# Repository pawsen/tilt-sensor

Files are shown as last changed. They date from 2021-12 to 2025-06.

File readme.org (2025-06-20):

#+TITLE: Readme

# Note that #+PROPERTY lines do not automatically take effect. You should either re-open the file or press C-c C-c on the line.
#+PROPERTY: ATTACH_DIR misc
#+PROPERTY: ATTACH_DIR_INHERIT t

Use an arduino for converting the output of an accelerometer to an angle of inclination.

* TL;DR

- Add 4.7㏀ as pullups between =SDA=, =SCL= and =Vcc= ::
  4-wire cables to connect the Arduino, LCD and accelerometer, =Vcc=, =gnd=, =SDA= and =SCL=.
  Use a small piece of stripboard to connect the cables:
  4 strips with minimum 5 rows. The rows are: pullups, accelerometer, arduino, power and connecting cable.
  On the Arduino:
  - =A4 - SDA=
  - =A5 - SCL=
- Update [[file:combined/combined.ino][combined.ino]] ::
  Run the accelerometer 2g test [[file:misc/calibrate/calibrate.ino][calibrate.ino]] to get the min/max static accelerations for the three axis and update the values
  - Optionally, use [[file:misc/i2c_scanner/i2c_scanner.ino][ic2_scanner.ino]] to get the addresses. If they are the default values, only the acceleration min/max values have to be updated.
  - Optionally, set the [[https://lastminuteengineers.com/i2c-lcd-arduino-tutorial/#i2c-address-of-lcd][I2C address of the LCD]]. The default is =0x27=.
  - Optionally, set the I2C address of the accelerometer. If it is [[*Accelerometer, ADXL345][ADXL345]], the default is =0x53=
- Optionally, print the cases in the =stl= directory

The cable between the two boxes can be a cat5 network cable (low-ish capacitance).
- one pair ground, one pair +5V, and SDA+GND and SCL+GND pairs.

In the =combined= directory run
#+begin_src sh
make upload
# open the serial console
tio -b 9600 /dev/ttyUSB0
#+end_src

The assembled system looks like
#+CAPTION: Display and sensor.
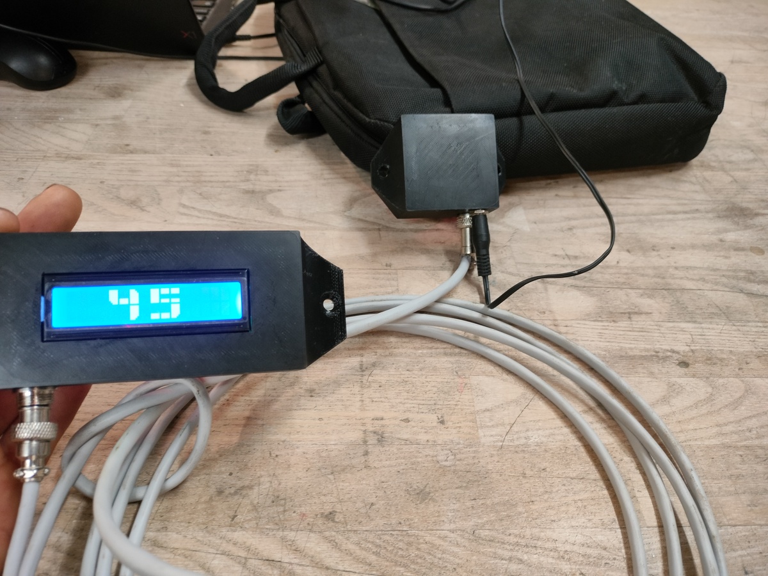
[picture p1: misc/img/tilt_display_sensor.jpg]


#+CAPTION: Backside of the LCD: 4-wire connection to I2C shield (PCF8574) for the 1602 LCD display
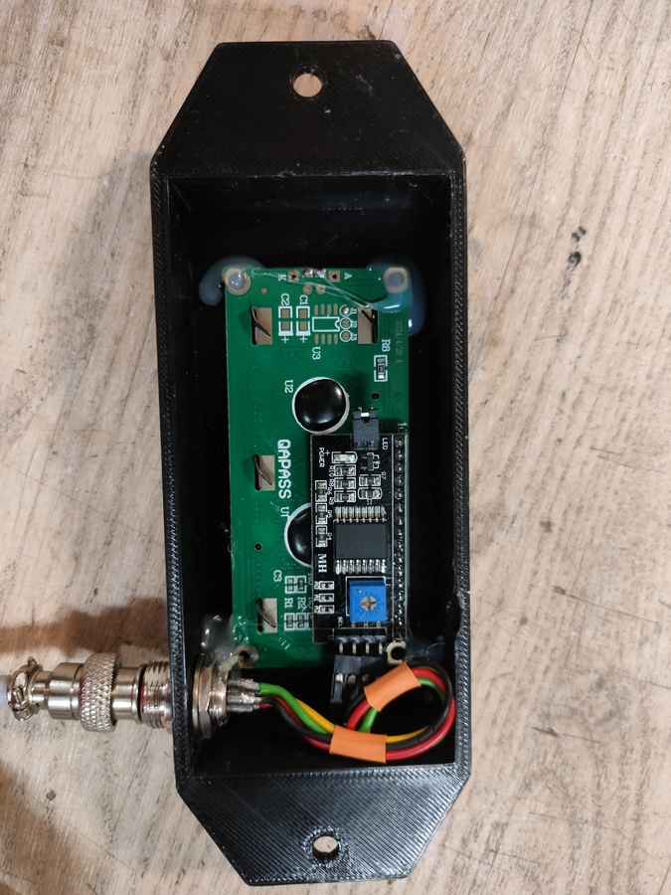
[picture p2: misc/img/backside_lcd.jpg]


#+CAPTION: Backside of the sensor: 4-wire connection, dc-barrel for power, ADXL345 accelerometer, arduino micro pro and stripboard with 4.7㏀ pullups and connectors.
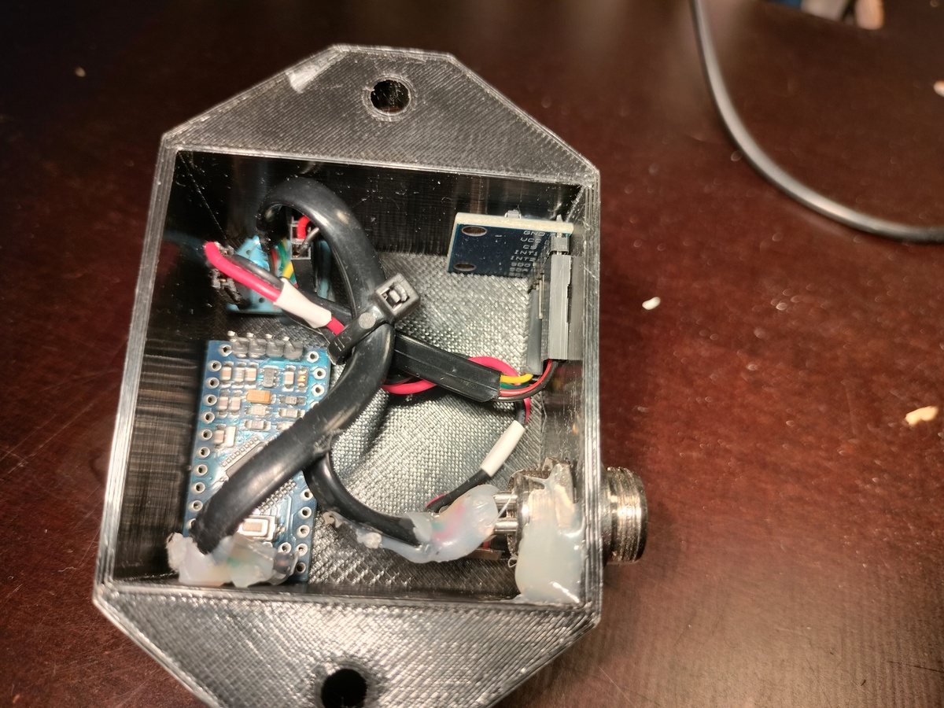
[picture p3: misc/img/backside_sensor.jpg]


The rise time, which is due to the capacitance of the random 4m cable shown above and connections, is seen by putting an oscilloscope on the =SCL= line and =gnd=. The Rise time =tf = 1.64μs= is higher than the allowed 1000ns(1μs) for I2C standard mode, but still works well at 100Hz. See sec. [[*Resistor sizing]] for more info.
#+CAPTION: SCL signal for the shown system, measured with an oscilloscope.
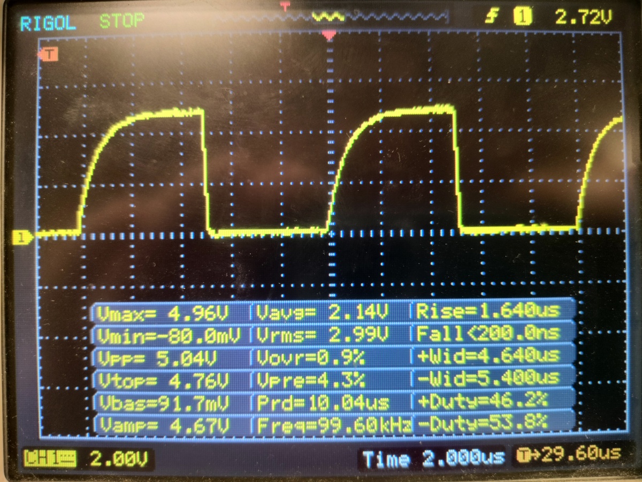
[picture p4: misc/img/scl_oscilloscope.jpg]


* Why use a accelerometer

One common way to determine the tilt of a system is to integrate the output of a gyroscope. But error associated with null bias stability can quickly compound as the integration period is increased, causing an apparent rotation even when the device is stationary.

For systems where the net acceleration is gravity, an accelerometer can be used to measure the static angle of tilt or inclination. The tilt is calculated from the projection of the gravity vector on the axes of the accelerometer.

Because gravity is a dc acceleration, any forces that result in an additional dc acceleration corrupt the output signal and result in an incorrect calculation.

- dc: gravity, constant acceleration (moving car) and centrifugal acceleration
- ac: vibrations

AC-response accelerometers are commonly designed from piezoelectric materials that produce an electrical output proportional to the acceleration.
DC accelerometers can also meassure vibrations, but the user has to deal with the zero-offset due to gravity and do the [[*Calibration / 2g turnover test][2g turnover test]]

* Calculate inclination
From [[https://www.analog.com/en/app-notes/an-1057.html][analog.com using an accelerometer for inclination sensing]] (or [[file:misc/an-1057-accelerometer-for-inclination-sensing.pdf][local copy]]),
** 2d
The angle of rotation θ in fig [[fig:2d_rotation]], can be calculated as the ratio of the projected accelerations,

$$ \frac{A_\text{X,out}}{A_\text{Y,out}} = \frac{1g⋅\sin(θ)}{1g⋅\cos(θ)} = \tan(θ) $$

#+NAME: fig:2d_rotation
#+CAPTION: Rotation for two axis tilt
[[file:misc/img/two_axis_tilt.svg]]

*** Sensitivity
One benefit of using two axis for calculating the rotation is that the sensitivity, the change in output for some change in input, is roughly constant.

For a single axis measurement, the sensitivity decreases as the angle increases.
#+begin_quote
You can imagine the sensor as a beam suspended on springs, with the capacitance between the beam and the support base giving the acceleration measurement. When the beam is perpendicular to the acceleration field small tilt changes will have a large effect as gravity acts over a larger area.

As the beam tilts vertically, the sensor becomes less sensitive (interacting with the gravity vector less) until, at full vertical orientation, it can not return a reading since the gravity vector has no effect on the beam.
#+end_quote

Fig. [[fig:1d_incremental_sensitivity]] shows the minimum necessary resolution when measuring the output acceleration in order to meet the desired inclination resolution for the entire range of an application.

For example, designing for a maximum step size of 1°, a resolution of at least 8 mg/LSB is necessary for a range of ±63°. A single axis measurement is unable to measure to ±90° tilt.

#+NAME: fig:1d_incremental_sensitivity
#+CAPTION: Incremental Inclination Sensitivity for 1° Step for a single axis.

[[file:misc/img/1axis_sensitivity.svg]]

For dual axis measurements, with constant sensitivity, fig. [[fig:2d_incremental_sensitivity]] shows the minimum resolution for a desired inclination step size. For 1° resolution, a sensitivity of 17.45mg/LSB is needed.

#+NAME: fig:2d_incremental_sensitivity
#+CAPTION: Minimum Accelerometer Resolution for a Desired Angle of Inclination Resolution for dual axis.
[[file:misc/img/2axis_sensitivity.svg]]
** 3d
The classical method of rectangular \( (x, y, z) \) to spherical (ρ, θ, φ) conversion can be used to relate the angle of tilt in the xy-plane, θ, and the angle of inclination from the gravity vector, φ, to the measured acceleration in each axis [[https://en.wikipedia.org/wiki/Spherical_coordinate_system#Cartesian_coordinates][as follows]]

$$ θ = \tan^{-1} \left( \frac{A_{X}}{A_{Y}}\right) $$
$$ φ = \cos^{-1} \left( \frac{A_Z} {\sqrt{A^{2}_{X} +  A^{2}_{Y} + A^{2}_{Z} }} \right) $$

θ is calculated from the ratio of two orthogonal axes and have roughly constant sensitivity. φ is calculated from a single axis(the denominator can be replaced with a constant, ideally 1g) and have the single axis sensitivity.

Another way to calculate the inclinations are

$$ θ = \tan^{-1} \left( \frac{A_{X}} { \sqrt{A^{2}_{Y} + A^{2}_{Z}} } \right) $$
$$ ψ = \tan^{-1} \left( \frac{A_{Y}}{ \sqrt{A^{2}_{X} + A^{2}_{Z}} } \right) $$
$$ φ = \tan^{-1} \left( \frac{ \sqrt{A^{2}_{X} + A^{2}_{Y}} }{A_{Z}} \right) $$

- θ as the angle between the horizon and the x-axis
- ψ as the angle between the horizon and the y-axis
- φ as the angle between the gravity vector and the z-axis.

as seen below
#+CAPTION: Angles in a spherical coordinate system
[[file:misc/img/3d_independent_inclination.svg]]

Because the inverse tangent function and a ratio of accelerations is used, the benefits mentioned in the dual-axis example apply, namely that the effective incremental sensitivity is constant and that the angles can be accurately measured for all points around the unit sphere.

** Calibration / 2g turnover test
The calibrated accelerometer output is

$$ A_\text{out} = A_\text{off} + (Gain * A_\text{actual}) $$

The offset and gain are calculated as

$$ A_\text{off} = 0.5 (A_\text{+1g} + A_\text{-1g}) $$
$$ Gain = 0.5 \left( \frac{  A_\text{+1g} + A_\text{-1g} }{1g} \right) $$

where $A_\text{+1g}$ and $A_\text{-1g}$ are the measured max- and min gravity along an axis.

Use [[file:misc/calibrate/calibrate.ino][calibrate.ino]] to get the measurements and update the values in [[file:combined/combined.ino][combined.ino]].
Measure the min and max "static" acceleration by holding the accelerometer on all sides at the top/bottom and edge of a table. Alternatively, tape it to a small wooden block and press against the table.

* Accelerometer, ADXL345
The [[https://www.analog.com/media/en/technical-documentation/data-sheets/ADXL345.pdf][ADXL345]]([[file:misc/ADXL345.pdf][local copy]]) in a breakout package.

- Current consumption depends on the Output Data Rate(ODR), p. 13 in data sheet. This can be set with ~setRate()~ from the [[https://github.com/jrowberg/i2cdevlib/tree/master/Arduino/ADXL345][library]].
  Default is =ADXL345_RATE_100= with a consumption of 140μA, the minimun is 23μA for rates of 0.39Hz and below.
- The sensitivity depends on the resolution(10-13 bit) and range (2g, 4g, 8g, 16g), see p. 3.
  For full resolution the sensitivity is typical 3.9mg/LSB, with [3.5-4.3]mg/LSB being min and max. From fig [[fig:2d_incremental_sensitivity]] this gives and angle inclination step size of at least 0.25°.
- The I2C address depends on the =SDO= pin which is pulled down with a 4.7K resistor.
  Unconnected the address is =0x53=, if connected to *3.3V* the line is pulled high and the address is =0x1D=.

As an example, the following set the resolution to 10bit and the range to 16g, giving a scale factor of [28,6-34.5]mg/LSB. (I do not know why you would limit the resolution to 10bit, unless also setting the range to 2g, or doing a self-test as in [[file:misc/selftest.ino][selftest.ino]])
#+begin_src c
#include <ADXL345.h>

// the default i2c address is 0x53. Defined in ADXL345.h
// ADXL345_ADDRESS_ALT_LOW => 0x53
// ADXL345_ADDRESS_ALT_HIGH => 0x1D
ADXL345 accel(ADXL345_ADDRESS_ALT_LOW);

// 0 => 10 bit mode, 1 => resolution increases with the g range set by the range
// bits to maintain a 4 mg/LSB scale factor.
accel.setFullResolution(0);
accel.setRate(ADXL345_RATE_100); // default
accel.setLowPowerEnabled(0);
accel.setRange(3); // 0=>2g, 1=>4g. 2=>8g, 3=>16g
#+end_src

[[https://youtu.be/3KPzLbZTdrA][Here is deep dive into MEMS devices on youtube]].

* Monitor the serial port
** Configure permissions for serial port
The tty devices are usually readable/writable by a specific group such as =dialout=. Add yourself to that group to gain access to all serial ports
: sudo gpasswd -a YourUsername dialout

Or do a one-time temporary manual change
: sudo chmod a+rw /dev/ttyUSB0

*** udev rules on NixOS

Make a udev rule to get a "static" symlink to the device

Start by getting the vendor- and product id of the attached arduino
#+begin_src sh
> nix shell nixpkgs#usbutils
> lsusb

Bus 001 Device 078: ID 2341:0043 Arduino SA Uno R3 (CDC ACM)
#+end_src

The udev rule
#+begin_src nix
services.udev.packages = [
      (pkgs.writeTextFile {
        name = "50-arduino.rules";
        text = ''
          SUBSYSTEMS=="tty", ATTRS{idVendor}=="2341", ATTRS{idProduct}="0043", MODE="0666", TAG+="uaccess", SYMLINK+="arduino"
          # or matching most arduinos, incl clones
          KERNEL=="ttyACM[0-9]*", MODE="0666", TAG+="uaccess", ...
        '';
        destination = "/etc/udev/rules.d/50-zsa.rules";
      })
    ];
#+end_src

Make sure the =udev rules= are reloaded
#+begin_src sh
udevadm trigger
udevadm control --reload-rules
#+end_src
Alternatively, try to reboot.

The match keywords for
- =KERNEL= - match against the kernel name for the device
- =SUBSYSTEM= - match against the subsystem of the device

can be found by
#+begin_src sh
udevadm info -q property /dev/ttyACM0

DEVNAME=/dev/ttyACM0
SUBSYSTEM=tty
ID_VENDOR_ID=2341
ID_USB_MODEL_ID=0043
...
#+end_src
~DEVNAME~ is the ~KERNEL~ attribute. This can be seen by
#+begin_src sh
udevadm info --attribute-walk /dev/ttyACM0

looking at device '/devices/pci0000:00/0000:00:14.0/usb1/1-1/1-1:1.0/tty/ttyACM0':
  KERNEL=="ttyACM0"
  SUBSYSTEM=="tty"
#+end_src

The ~TAG+="uaccess"~ is from the [[https://wiki.archlinux.org/title/Udev#Allowing_regular_users_to_use_devices][archlinux wiki on udev:]]
#+begin_quote
The modern recommended approach for systemd systems is to use a MODE of 660 to
let the group use the device, and then attach a TAG named uaccess. This special
tag makes udev apply a dynamic user ACL to the device node, which coordinates
with systemd-logind(8) to make the device usable to logged-in users.

*Note*: For any rule adding the uaccess tag to be effective, the name of the
file it is defined in has to lexically precede
/usr/lib/udev/rules.d/73-seat-late.rules.
#+end_quote
** Read from the serial port
For bidirectional
: screen /dev/ttyACM0
[[https://gist.github.com/jctosta/af918e1618682638aa82][Screen cheatsheet]]

Or for only reading, using a makefile (or a script)
#+begin_src makefile
monitor:
         stty -F $(MONITOR_PORT) raw $(MONITOR_BAUDRATE)
         cat $(MONITOR_PORT)
#+end_src
where ~MONITOR_BAUDRATE~ is set in the arduino sketch.
* I2C between the two boxes
The arduino, accelerometer and display uses I2C for communication. I2C is not meant for long cables(>2m). For longer distances

- Using a low capacitance cable (twisted-pair/Ethernet);
- Limiting the bus speed;
- Having pull-ups that are correctly sized.

For a Cat5 cable wire it as:
- one pair ground, one pair +5V, and SDA+GND and SCL+GND pairs.

https://www.gammon.com.au/forum/?id=10896
** Brief intro
I2C has several speed modes
- Standard-mode (Sm), up to 100 kilobits per second (kbps).
- Fast-mode (Fm), up to 400 kbps
- Fast-mode Plus (Fm+), up to 1 Mbps

Additional there are two modes that requires controller code, active pullups or similar
- High-speed mode (Hsm), up to 3.4 Mbps
- Ultra-Fast mode (UFm), read only, up to 5 Mbps

The default for an arduino is =Sm=. To see if targets are able to communicate at higher speed modes, use the [[https://github.com/RobTillaart/Arduino/tree/master/sketches/MultiSpeedI2CScanner][MultiSpeedI2CScanner]].
For both I2C and SPI(serial peripheral interface), the master determines the bus speed and you can set it to whatever you like(up to the supported mode). Generally, SPI runs faster than I2C but requires more signals and cables.
I2C is half-duplex communication where only a single controller or a target device is sending data on the bus at a time. In comparison SPI is a full-duplex, i.e. data can be sent and received at the same time.

** Registers

The I2C/2-wire Serial interface(TWI) hardware in ATmega MCU uses registers TWBR, TWCR, TWSR, TWDR, TWAR, and TWAMR to configure the hardware and to transmit and receive data. See [[https://www.arnabkumardas.com/arduino-tutorial/i2c-register-description/][this link]] for a description of the registers.

#+CAPTION: AVR I2C Register Configuration
[[file:misc/img/atmega16_32_twi_module.webp]]

*** change timing / speed

The I2C speed is set by
#+begin_src cpp
// initialize Wire or some library using Wire for communication
Wire.begin();
// or
lcd.init();  // there is a Wire.begin() in the lcd.init() function

// frequency in Hz
Wire.setClock(400000L);
#+end_src

[[https://github.com/arduino/ArduinoCore-avr/blob/master/libraries/Wire/src/Wire.cpp#L85-L88][Wire.setClock()]] calls [[https://github.com/arduino/ArduinoCore-avr/blob/master/libraries/Wire/src/utility/twi.c#L139-L147][twi_setFrequency()]] where the =TWBR= (Two Wire Bit Rate register of the MCU) variable is set. The relationship between =TWBR= and frequency is

: slc_freq = cpu_clock / (16 + (2 * TWBR * prescaler))
the =cpu_clock= is 16MHz for the ATmega328 used by Arduino

| TWBR | prescaler | Frequency                                |
|------+-----------+------------------------------------------|
|   12 |         1 | 400   kHz  (maximum supported frequency) |
|   32 |         1 | 200   kHz                                |
|   72 |         1 | 100   kHz  (default)                     |
|  152 |         1 | 50   kHz                                 |
|   78 |         4 | 25   kHz                                 |
|  158 |         4 | 12.5 kHz                                 |

~Wire.setClock~ should be used as it is portable, however it does not change the prescaler and the argument to ~Wire.setClock~ is ~uint32_t~ (unsigned int). Thus the frequency cannot be changed arbitrarily. As seen from the link to [[https://github.com/arduino/ArduinoCore-avr/blob/master/libraries/Wire/src/utility/twi.c#L139-L147][twi_setFrequency()]] there are no limit checks, it only works for speeds between 50-400kHz.

For speeds below 50kHz, =TWBR= and optionally the prescaler, has to be set manually. The prescaler is set by the =TWPS0= and =TWPS1= bits, the relationship is

: prescaler = 4^TWPS
| TWPS1 | TWPS0 | TWPS | prescaler |
|-------+-------+------+-----------|
|     0 |     0 |    0 |         1 |
|     0 |     1 |    1 |         4 |
|     1 |     0 |    2 |        16 |
|     1 |     1 |    3 |        64 |

To set the prescaler to 4 you need to set the bit TWPS0 in TWSR, so for example to have a clock of 12.5 kHz:
#+begin_src c
Wire.begin ();
TWBR = 158;
TWSR |= bit (TWPS0);
#+end_src

*** Broadcast
From [[https://www.ti.com/lit/an/sbaa565/sbaa565.pdf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][TI: A Basic Guide to I2c, reserved addreses]] broadcast is done by writing to address 0.

For it to work, the last bit of the TWAR (TWI (Slave) Address Register) has to be set. The 7 most significant bits of TWAR is the address, the last is TWGCE (TWI General Call Recognition Enable Bit). See [[http://www.gammon.com.au/i2c#reply1][example]]

#+CAPTION: Enable slave to recieve broadcast
#+begin_src c
#include <Wire.h>
const byte MY_ADDRESS = 42;   // me
void setup ()
{
    Wire.begin (MY_ADDRESS);  // initialize hardware registers etc.
    TWAR = (MY_ADDRESS << 1) | 1;  // enable broadcasts to be received

    Wire.onReceive(receiveEvent);  // set up receive handler
    pinMode(LED, OUTPUT);          // for debugging, allow LED to be flashed
}
#+end_src

** Resistor sizing
*** tl;dr
Use 4.7㏀ between =SDA=, =SCL= and =Vcc=. You can leave the internal pullups enabled. The pullups works in parallel, thus the effect of the internal pullups is to reduce the 4.7㏀ slightly, which should not be a problem.

*** info
I2C is a open drain bus and requires pullups between =SDA=, =SCL= and =Vcc=.

#+CAPTION: Open-Drain Connection Pulls Line Low When NMOS is Turned On
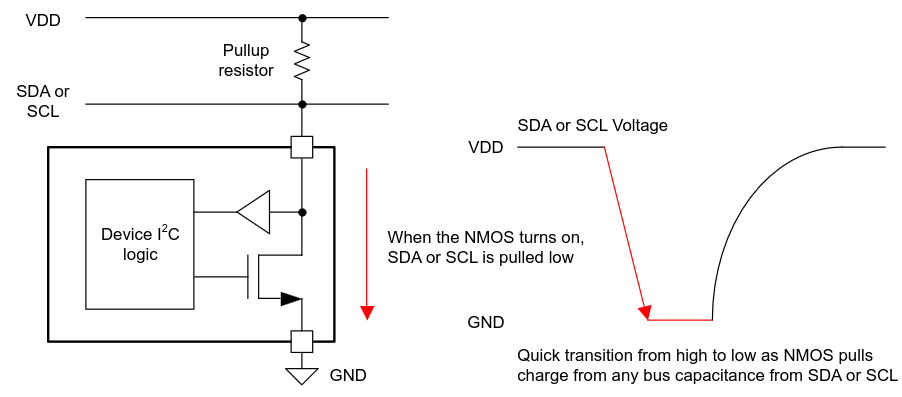
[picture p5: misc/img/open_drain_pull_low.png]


#+CAPTION: Pullup Resistor Pulls Line High When NMOS is Turned Off
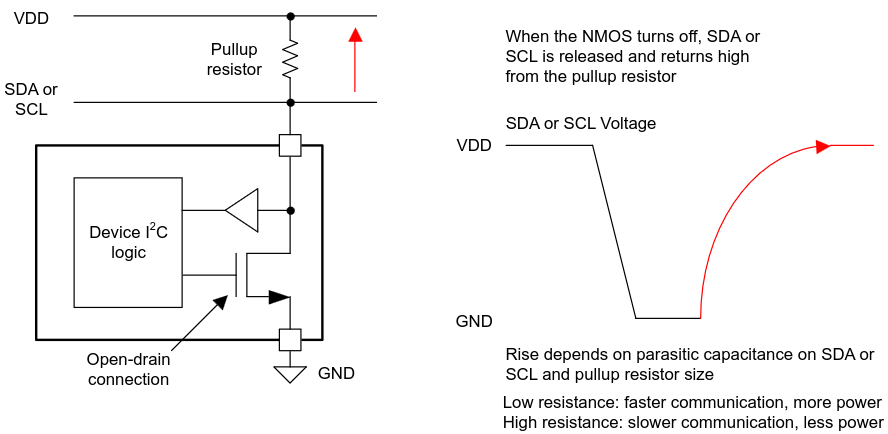
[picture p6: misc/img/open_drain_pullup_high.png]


The normal pullup resistor recommendation is 1 kΩ to 10 kΩ. With higher resistances, the I2C communication is slower. With lower resistances, the I2C communication requires more power. Based on the several different parameters, a minimum and maximum resistance can be calculated for the I2C bus speed.

The maximum "low level output" voltage is V_OL = 0.4V. For a 5V system this gives a minimum resistance of
$$ R_\text{min} = \frac{V_\text{CC} - V_\text{OL}} {I_\text{OL}} = \frac{5V - 0.4V}{3mA} ≅ 1.5 ㏀ $$

The maximum resistance is based on the requirement for the rise time and bus capacitance given in the table below

#+CAPTION: Parametric Characteristics From I2C Protocol
| Parameter                                 | Standard-mode | Fast-mode | Fast-mode Plus | Unit |
|-------------------------------------------+---------------+-----------+----------------+------|
| fSCL, SCLK clock frequency                |      0 to 100 |  0 to 400 |      0 to 1000 | kHz  |
| tr, Rise time of both SDA and SCL signals |          1000 |       300 |            120 | ns   |
| Cb, Capacitive load for each bus line     |           400 |       400 |            550 | pF   |

The [[https://www.ti.com/lit/an/sbaa565/sbaa565.pdf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][formula]] (the 0.8473 constant is because the signal does not have to go from 0V-Vcc, but instead 0.3Vcc-0.7Vcc which are the Low and high level input voltage):
$$ R_\text{max} = t_\text{rise} / (0.8473 Cb) $$

For Standard mode, with tr=1ns and maximum allowed capacitance of Cb=400pF, the maximum resistance is 750Ω which is lower than the minimum resistance of 1.5㏀ for a 5V system.
For this reason the maximum recommended bus capacitance is dropped down to about 200pF with a 5 volt system

Fig. [[fig:i2c_100kHz_pullups]] shows measurements of T_rise for different pullup resistors. As a general recommendation 4.7㏀ works well.

#+NAME: fig:i2c_100kHz_pullups
#+CAPTION: T_rise and the size of pullup resistor for 100kHz clock.
#+CAPTION: 68k, 47k, 33k, 10k, 6.8k,4.7k, 3.3k, 2.2k and 1.5k resistor size
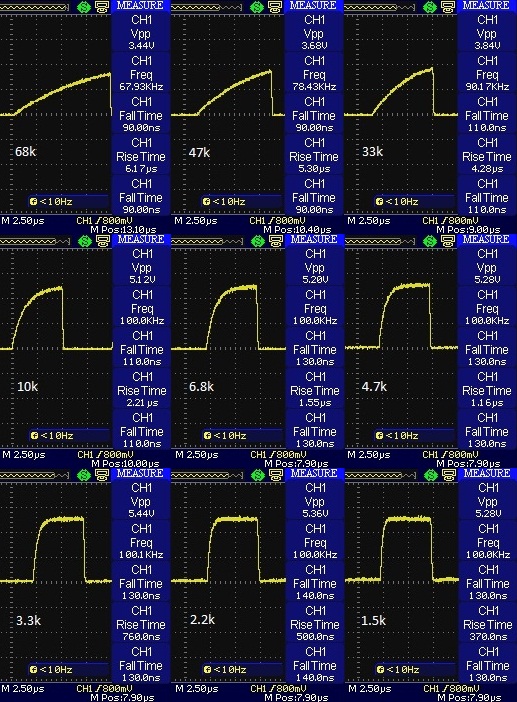
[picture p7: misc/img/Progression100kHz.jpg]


See [[https://web.archive.org/web/20150923044740/http://dsscircuits.com:80/articles/effects-of-varying-i2c-pull-up-resistors][link]](especially for 400kHz, where 4.7㏀ resistor is needed to reach that frequency) and [[http://www.gammon.com.au/i2c#reply5][link2]] for additional measurements.

Power Rating: The power consumed in a resistor is \( V⋅I = V^2R \). For a 5.5V drop and 1k that's less than 31mW. So there should not be an issue for discrete components.

As a final note, CAT5 can't have a higher capacitance than 52pf/m, or it isn't CAT5.
- one pair ground, one pair +5V, and SDA+GND and SCL+GND pairs.

* Other resources
- [[https://www.best-microcontroller-projects.com/magnetometer-tilt-compensation.html][Using an accelerometer as tilt-compensation for a compass/magnetometer]]
- [[https://github.com/alex-hhh/Arduino_Inclinometer][Arduino based inclinomte]] ::  a device that displays roll and pitch inside a vehicle.

** libraries
https://github.com/RobTillaart/Arduino
https://github.com/jrowberg/i2cdevlib

LCD API
https://playground.arduino.cc/Code/LCDAPI/
https://maxpromer.github.io/LCD-Character-Creator/

https://bitbucket.org/teckel12/arduino-lcd-bitmap/wiki/Home

SoftwareSerial alternative
https://forum.arduino.cc/t/can-arduino-handle-multiple-serial-spi-i2c-softwareserial-at-one-sketch/298978
https://www.arduino.cc/en/Reference/softwareSerial
https://arduino.stackexchange.com/questions/34126/whats-the-difference-between-all-the-software-serial-libraries-which-one-is-ar

Orignal NeoSWSerial does not compile on Pro Micro
https://github.com/SlashDevin/NeoSWSerial/issues/3
That is fixed in this clone
https://github.com/SRGDamia1/NeoSWSerial

Supported Library Values:
    Ethernet
    EEPROM
    Firmata
    GSM
    LiquidCrystal
    SD
    Servo
    SPI
    SoftwareSerial
    Stepper
    TFT
    WiFi
    Wire

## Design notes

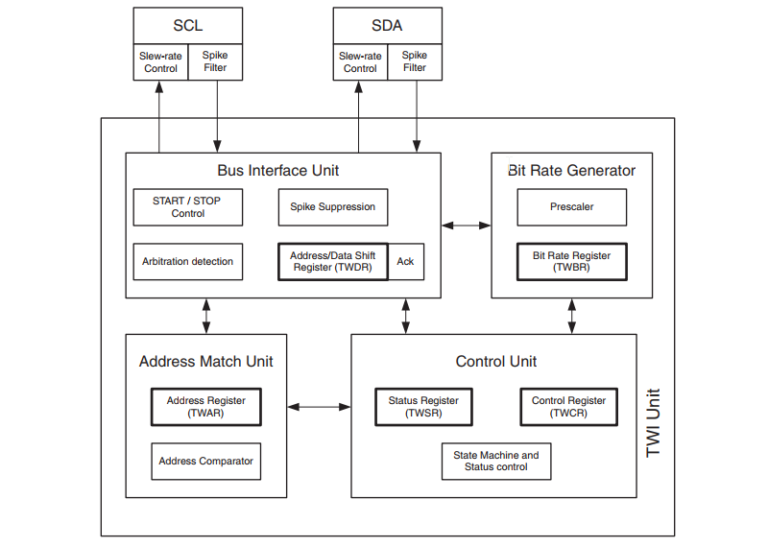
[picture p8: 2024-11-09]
misc/img/atmega16_32_twi_module.webp

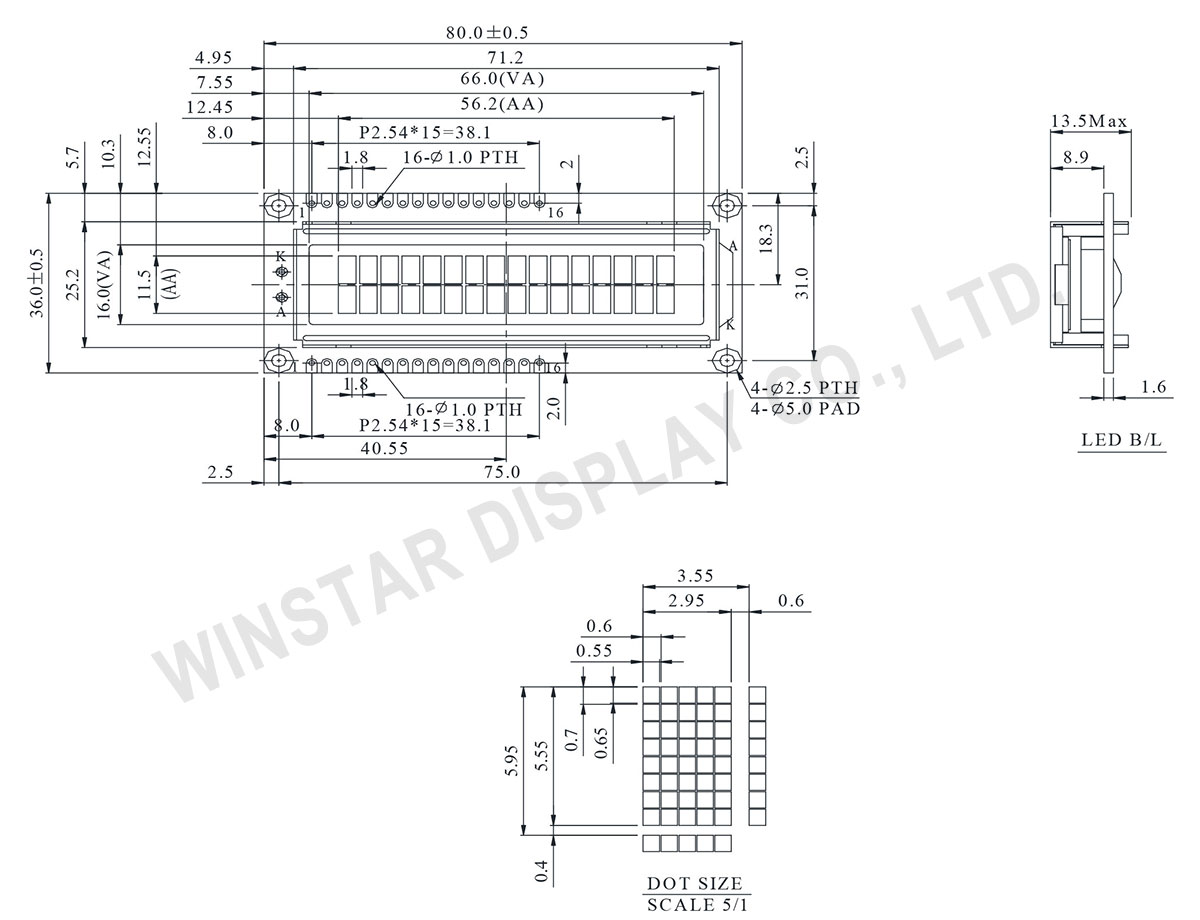
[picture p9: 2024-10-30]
stl/WH1602W.jpg

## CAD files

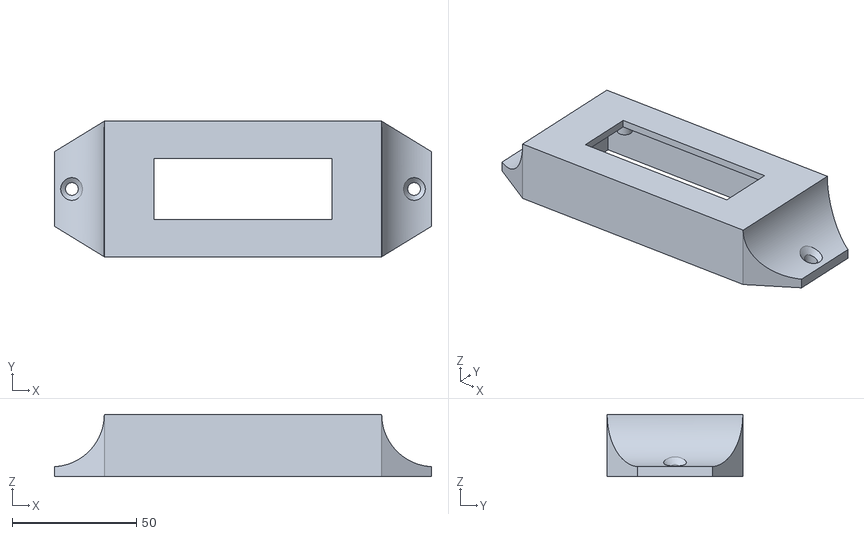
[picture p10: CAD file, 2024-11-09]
stl/case-lcd.stl
151.5 x 54.5 x 25.0

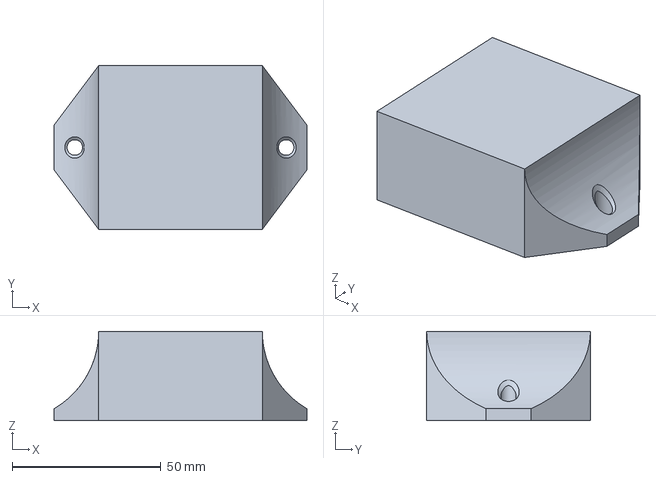
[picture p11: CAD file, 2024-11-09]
stl/case.FCStd
85.0 x 55.0 x 30.0 mm

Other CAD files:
stl/case-acc.stl
stl/case.3mf

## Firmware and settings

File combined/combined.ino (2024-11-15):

// sensor
#include <Wire.h>
#include <Adafruit_Sensor.h>
#include <Adafruit_ADXL345_U.h>
#include <SimpleKalmanFilter.h>
// display
#include <LiquidCrystal_I2C.h>
#include <BigCrystal.h>
// display extra sensor info
#include "extra.h"

// set the LCD address to 0x27 for a 16 chars and 2 line display
LiquidCrystal_I2C lcd(0x27, 16, 2);
BigCrystal biglcd(&lcd);

/* Assign a unique ID to this sensor at the same time */
Adafruit_ADXL345_Unified accel = Adafruit_ADXL345_Unified(12345);

/* Calibrate accelerometer using two-point measurement
 *
 * meassure min and max "static" acceleration by taping the accelerometer to a
 * rectangular block and put it on all sides on a table. Tip: On the two sides
 * where the acc.meter and cables are in the way, press the block against the
 * bottom of the table. */

// gravity defined in Adafruit_Sensor to be 9.806 m/s^2
const float g = SENSORS_GRAVITY_EARTH;
// measured "static" accelerations
const float minX = -10.90;
const float maxX = 10.28;
const float minY = -10.47;
const float maxY = 10.16;
const float minZ = -8.36;
const float maxZ = 11.41;

float offset(float min_acc, float max_acc){
    return 0.5 * (min_acc + max_acc);
}
float gain(float min_acc, float max_acc){
    return 0.5 * ((max_acc - min_acc) / g);
}

const float offsetX = offset(minX, maxX);
const float offsetY = offset(minY, maxY);
const float offsetZ = offset(minZ, maxZ);

const float gainX = gain(minX, maxX);
const float gainY = gain(minY, maxY);
const float gainZ = gain(minZ, maxZ);

// buffer for displaying roll
const uint8_t bufsize = 33;
boolean runOnce = false;


/* get calibrated accelerations */
void get_cal_acceleration(sensors_event_t *event, sensors_vec_t *vec){
    vec->x = (event->acceleration.x - offsetX)/gainX;
    vec->y = (event->acceleration.y - offsetY)/gainY;
    vec->z = (event->acceleration.z - offsetZ)/gainZ;
}

/* get averaged accelerations */
void get_avg_acceleration(sensors_event_t *event, sensors_vec_t *vec, uint8_t n) {
    float ax,ay,az;
    uint8_t i;

    ax=0; ay=0; az=0;
    for(i=0; i<n; i++) {
        accel.getEvent(event);
        get_cal_acceleration(event, vec);
        ax += vec->x;
        ay += vec->y;
        az += vec->z;
        // Don't read faster than 100Hz: (10*100ms=1s 1s/10=100ms)
        delay(100);
    }
    vec->x = ax/n; vec->y = ay/n; vec->z = az/n;
}

void orientation(sensors_vec_t vec, sensors_vec_t *val){
    /* roll;
       Rotation around the longitudinal axis (the plane body, 'X axis').
       Roll is positive and increasing when moving downward. -90 degrees <= roll
       <= 90 degrees */
    /* pitch;
      Rotation around the lateral axis (the wing span, 'Y axis').
      Pitch is positive and increasing when moving upwards. -180 degrees <=
      pitch <= 180 degrees) */
    /* heading;
      Angle between the longitudinal axis (the plane body) and magnetic north,
      measured clockwise when viewing from the top of the device. 0-359
      degrees */
    // θ, theta: rotation of x-axis
    // ψ, psi: y-axis
    // φ, phi: z-axis

	// Because the inverse tangent function and a ratio of accelerations is
	// used, the benefits of the dual-axis apply, namely that the effective
	// incremental sensitivity is constant and that the angles can be accurately
	// measured for all points around the unit sphere

    // val->pitch = (int) (180/M_PI) *
	// 	atan2(vec.x, sqrt(vec.y*vec.y + vec.z*vec.z)) ;
    // val->roll = (int) (180/M_PI) *
	// 	atan2(vec.y, sqrt(vec.x*vec.x + vec.z*vec.z));
	// // we are only interested in abs angle
	// val->pitch  = abs(val->pitch);
	// val->roll  = abs(val->roll);

	//  XXX For this project I only care about rotation of a single plane and I
	//  only care about tilt from vertical, ie the interval [0, π/2]
	float theta =  abs( atan(vec.x / vec.y) );
	theta = min(theta, M_PI  - theta );
	val->roll = (int)(180 / M_PI) * theta;
}

void print_acceleration(sensors_vec_t vec){
    /* Display the results (acceleration is measured in m/s^2) */
    Serial.print("X: "); Serial.print(vec.x); Serial.print("  ");
    Serial.print("Y: "); Serial.print(vec.y); Serial.print("  ");
    Serial.print("Z: "); Serial.print(vec.z); Serial.print("  ");
    Serial.println("m/s^2 ");
}

void print_orientation(sensors_vec_t vec){
    Serial.print("θ: "); Serial.print(vec.roll); Serial.print("  ");
    Serial.print("φ: "); Serial.print(vec.pitch); Serial.print("  ");
    Serial.println("");
}

void setup(void) {
    Serial.begin(9600);

    biglcd.init();
    lcd.backlight();
    lcd.setCursor(0,0);
    lcd.print("Kilter Board  @");
    // Go to column 3, row 1
    lcd.setCursor(3,1);
    lcd.print("Beta Boulders");

    /* Initialise the sensor */
    if(!accel.begin()) {
        Serial.println("no ADXL345 detected ... Check your wiring!");
        lcd.setCursor(0,1);
        lcd.print("Error");
        while(1);
    }

    /* Set the range to whatever is appropriate for your project */
    // accel.setRange(ADXL345_RANGE_16_G);
    // accel.setRange(ADXL345_RANGE_8_G);
    // accel.setRange(ADXL345_RANGE_4_G);
    accel.setRange(ADXL345_RANGE_2_G);
#ifdef DEBUG
    /* Display some basic information on this sensor */
    displaySensorDetails(&accel);
    /* Display additional settings (outside the scope of sensor_t) */
    displayDataRate(&accel);
    displayRange(&accel);
#endif

    Serial.println("ready");
    delay(2000);
}

void loop(void) {
    sensors_event_t event;
    sensors_vec_t acc;
    sensors_vec_t ori;

    /* Get a new sensor event */
    //accel.getEvent(&event);
    //acceleration(event, &acc);
    get_avg_acceleration(&event, &acc, 5);
    orientation(acc, &ori);

#ifdef DEBUG
    print_acceleration(acc);
    print_orientation(ori);
#endif

    int tilt = (int)ori.roll;
    // int tilt = (int)ori.pitch;
    if (!runOnce) {
        runOnce = true;
        lcd.clear();
    }
    char pbuf[bufsize];
    char bbuf[bufsize];
    // right justify to center number
    sprintf(pbuf, "%2d", tilt);
    // pad with spaces (left justify), to clear left-over text
    sprintf(bbuf, "%-6s", pbuf);
    biglcd.printBig(bbuf, 4, 0);
    // remember to send '\n' or parsing will fail on the other arduino
    Serial.println(bbuf);
}

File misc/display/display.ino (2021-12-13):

#include <LiquidCrystal_I2C.h>
#include <BigCrystal.h>

const uint8_t bufsize = 33;
char buffer[bufsize];
boolean runOnce = false;

// set the LCD address to 0x27 for a 16 chars and 2 line display
LiquidCrystal_I2C lcd(0x27, 16, 2);
BigCrystal biglcd(&lcd);

// check for data on a given port.
// Most interfaces that derives from Stream (Serial, SoftwareSerial, etc) can be used
int recieve_data(Stream &port, char* buffer, int bufsize){

    uint8_t i = 0;
    while (port.available() > 0) {
        if (i < bufsize - 1){
            char ch = port.read();
            buffer[i] = ch;
            if (ch == '\n' && i > 0){
                // replace newline with null terminated
                buffer[i] = '\0';
                Serial.println("Recieved"); Serial.println(buffer);
                return 0;
            } else if (ch == '\n' && i == 0) {
                // only recieved newline
                return -1;
            }
            i++;
        }
    }
    // error. Either too many chars or no newline char
    return -1;
}

void setup() {
    Serial.begin(9600);

    biglcd.init();
    lcd.backlight();
    lcd.setCursor(0,0);
    lcd.print("Kilter Board  @");
    // Go to column 3, row 1
    lcd.setCursor(2,1);
    lcd.print("beta Boulders");

    Serial.println("ready");
    delay(2000);
}


void loop() {
    // check if there's data on the Serial interface
    if (recieve_data(Serial, buffer, bufsize) == 0){
        // clear the initial message now that we recieved data
        if (!runOnce) {
            runOnce = true;
            lcd.clear();
        }
        char pbuf[bufsize];
        // right justify to center number
        sprintf(pbuf, "%2s", buffer);
        // pad with spaces (left justify), to clear left-over text
        sprintf(buffer, "%-6s", pbuf);
        biglcd.printBig(buffer, 4, 0);
    }
    
    // we need a delay to ensure correct recieving SoftwareSerial
    // I don't know if the delay is need for Serial
    delay(100);
}

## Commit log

2021-12-13 Squashed 'lib/i2cdevlib/' content from commit 9c5d54e
    git-subtree-dir: lib/i2cdevlib
    git-subtree-split: 9c5d54e5d9bb65af0ee35e46800e5f9b342e8b55
    [biplane.obj, l.obj]
2021-12-13 misc programs: i2c scanner and BigCrystal example
2021-12-13 use one arduino for both meassuring and displaying tilt
2021-12-13 print Beta instead of beta
2024-10-30 feat: case for LCD and acc
    [cas-acc.stl, case-lcd.stl, case.3mf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]
2024-11-15 update readme and only use [0,π/2] as tilt interval
